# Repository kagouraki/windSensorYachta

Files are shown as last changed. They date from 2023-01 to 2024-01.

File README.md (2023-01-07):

## Windsensor Yachta

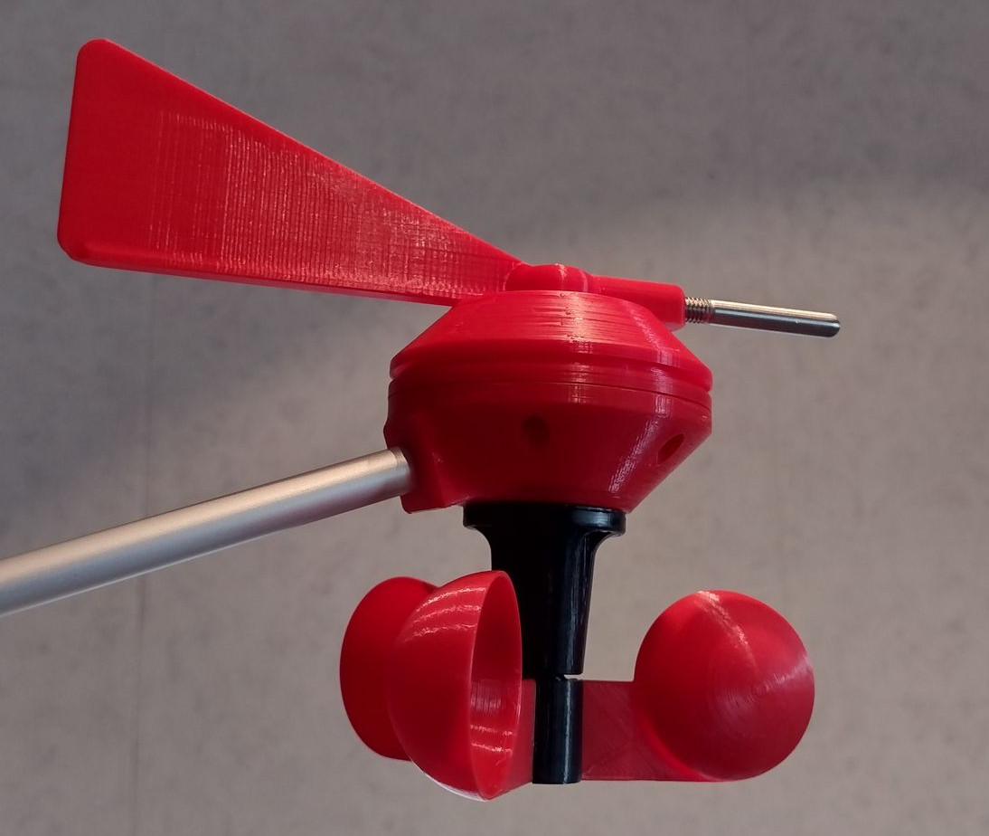
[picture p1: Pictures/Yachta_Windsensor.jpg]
Windsnesor Yachta


Image: Wind Sensor Yachta

The initial idea for the Yachta wind sensor is based on a work by the user Yachta. He presented and published the wind sensor on [Thingiverse](https://www.thingiverse.com/thing:2261719). Udo took up the idea of Yachta and modified the mechanics a little. The arms of the cup wheel have been separated. This makes 3D printing easier to implement. The electronics were completely redesigned by him. The microcontroller was removed and replaced with an ESP8266. A DC/DC converter module was installed so that the wind sensor can also be operated at 12V. The circuit board was created with the Windows software Sprint Layout and converted into Gerber files. Now is a new BCP available from Norbert.

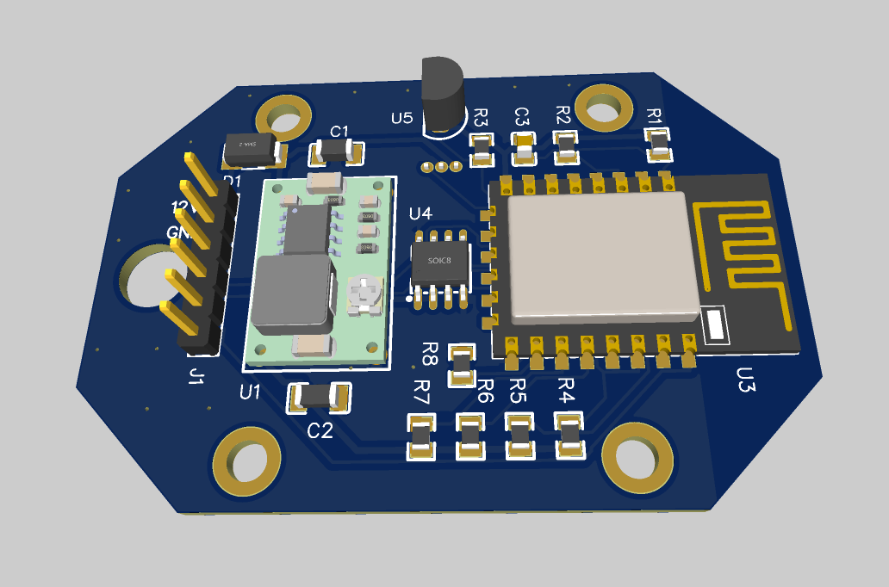
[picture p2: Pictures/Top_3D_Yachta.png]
Windsnesor Yachta


Image: PCB board

The PCB project is listed on [Open Source Hardware Lab](https://oshwlab.com/) an can be edited with the webbased online [layout program EasyEDA](https://easyeda.com/norbert-walter/projects).

The board without components can be ordered from [Aisler](https://aisler.net/p/VTNPJWKQ) or direct in EasyEDA.

There are different firmware for the wind sensor. Both Udo and Julian ([Jukolein](https://github.com/jukolein/NMEA0183-Windsensor)) have created their own firmware versions with different functionality. Udo has also designed another wind sensor, which is a further development of the Yachta wind sensor. The functional principle and the electronics are identical. But you need a different board because the wind sensor is slimmer. Julian published the whole thing on [Github](https://github.com/jukolein/NMEA0183-Windsensor) and wrote his own firmware for the wind sensor, which can also be used for this wind sensor. 

The WiFi 1000 firmware is a firmware that can be used universally for various wind sensors and was originally developed by Norbert for the [WiFi 1000 wind sensor](https://gitlab.com/norbertwalter67/Windsensor_WiFi_1000). The current versions of the firmware can be found in the respective own repositories at Github and GitLab.

A lively exchange of experiences takes place in the German-speaking [sailing forum](https://www.segeln-forum.de/board194-boot-technik/board195-open-boat-projects-org/79131-windsensor-ii-iii/). You can also participate in English.

If you like to help or consider this project useful, please donate. Thanks for your support!

Donate (https://www.paypal.com/cgi-bin/webscr?cmd=_s-xclick&hosted_button_id=5QZJZBM252F2L)

## Technical characteristics

* Measuring wind speed and wind direction 
* Robust mechanics
* Without special metal parts
* All parts can be found in the hardware store
* Easy 3D parts
* Weight app. 210g
* Weatherproof and UV stable
* No cabling for sensor signals
* Digital signal transmission with WiFi only
* 12V power supply utilizing top light power cable
* Using a ESP8266 for WiFi and data handling
* Update rate 1 samples per second
* No onboard instrument required
* Visualisation in OpenPlotter via laptop, mobile fone or tablett
* Web interface for operation
* No extra software required (display is the browser)
* Supporting  NMEA 0183 protocol
* Firmware update via Internet

## Firmware characteristics

**Udo Firmware**
* Web configuration for IP settings port 80
* UDP port 2948
* UDP NMEA0183 telegram MWV

**Jukolein Firmware**
* Web configuration and grafical visualisation
* Webserver port 80
* UDP port 8080
* TCP port 8080
* UDP/TCP NMEA0183 telegram MWV
* Firmware update OTA via Arduino IDE

**Wifi 1000 Firmware**
* Web configuration and graphical visualisation
* Webserver port 80
* TCP port 6666
* TCP NMEA0183 telegram MWV, VWR, VPW, INF
* JSON http://192.168.4.1/json
* Firmware update via Internet
* Android App

## How can I use it?

I use the windsensor in combination with [OpenPlotter](http://www.sailoog.com/openplotter) on a Raspberry Pi 3B. OpenPlotter serves as access point for WiFi devices. The windsensor connects to OpenPlotter via WiFi and transmits the NMEA0183 data telegrams every second. The windsensor sends NMEA0183 telegrams. Check here [link](http://www.nmea.de/nmea0183datensaetze.html) for more information. 

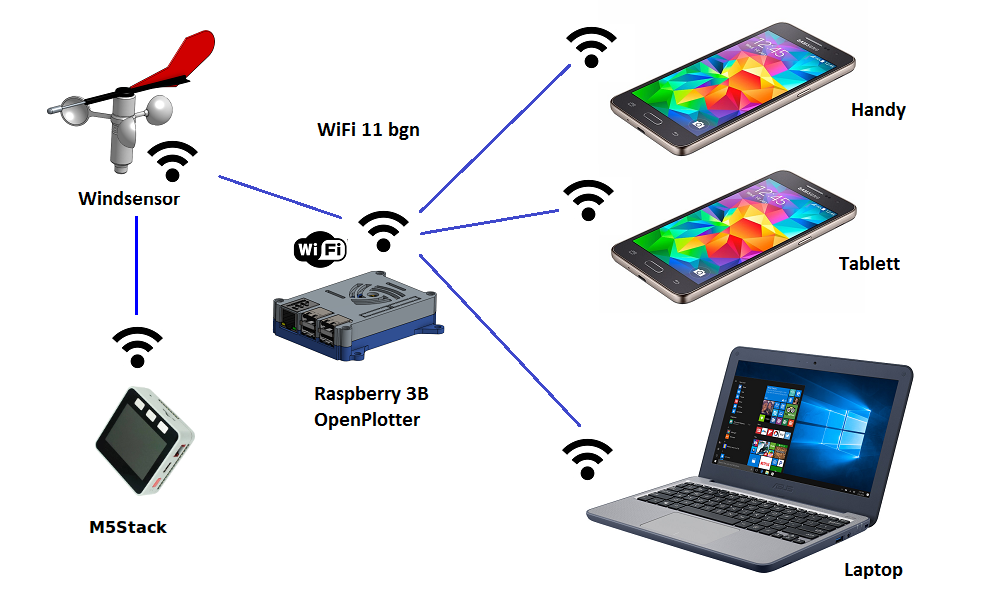
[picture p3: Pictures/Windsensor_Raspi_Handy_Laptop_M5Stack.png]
Connectivity


Img: Connection options

A Android App is also available. It is is a WebApp connecting directly to the windsensor to display all data.

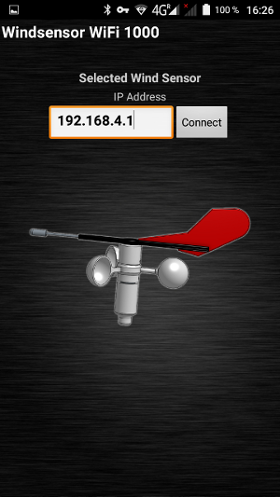
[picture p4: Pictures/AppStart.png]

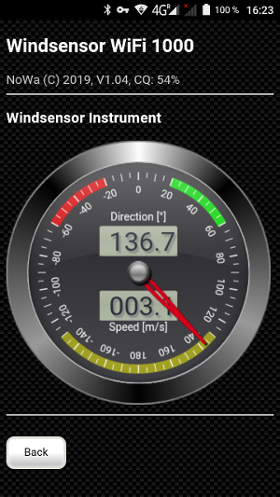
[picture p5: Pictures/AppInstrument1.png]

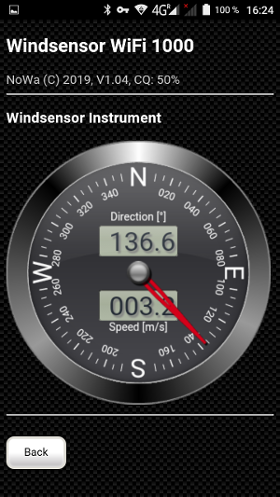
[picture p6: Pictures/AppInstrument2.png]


Img: Android App for Wifi 1000 firmware

## What is the current status?

I have completed many tasks but still not everything is perfect so far.

- [x] Technical recherche
- [x] Evaluation of function
    - [x] Hall sensors and rotation sensor
    - [x] Magnets
    - [x] Prototype circuit
    - [x] Test software
    - [x] Web display technologies
    - [x] 3D material test
    - [x] Coating tests
- [x] Mechanical design
    - [x] 3D parts
- [ ] Electronic design
    - [x] Circuit design
    - [x] Board design
    - [ ] Customer sample circuit
- [ ] Software
    - [x] Basic functionality
    - [x] NMEA0183 WiFi
    - [x] NMEA0183 Serial
    - [x] mDNS Service
    - [x] JSON
    - [ ] MQTT
    - [ ] Wind History Diagram
    - [x] Sensor Data Diagram for diagnostic and mechanical adjustment
    - [x] Web-Updater
    - [x] Web-Configurator
    - [x] Web server as data display
    - [x] Andoid App
    - [x] External Diagnostic Tool
	- [x] Support for other wind sensor types
- [x] Components ordering
    - [x] Electronic board
    - [x] Mechanical parts
    - [x] Fittings
- [x] Prototyp creation
    - [x] Yachta prototype
    - [x] Modifyed Yachta prototype
- [x] Production Zero series
    - [x] Assembled and programed PCB
- [x] Shipping Zero Series
- [ ] Documentation
    - [ ] Technical description
	- [x] Description Web frontend
    - [x] Construction manual
    - [x] Part list
    - [ ] User manual
    - [ ] Data sheet
- [ ] Application tests
    - [x] Temperature 20...80°C
    - [ ] Vibration test by strong wind (8bft)
    - [x] WiFi stability test
    - [x] Connection test
    - [ ] Rain test
    - [ ] IPX6 Water resistance test
    - [ ] UV radiation test
    - [ ] Long time test
    - [ ] Test with auto pilot
    - [x] User experiences
- [ ] Extensions
    - [x] Multi function display with M5Stack
    - [x] NMEA2000 Gateway
    - [x] Weather data sensor with BME280
- [ ] Certification
    - [ ] CE Certification

## Questions?

For questions or suggestions please get in contact via email at norbert-walter(at)web.de.

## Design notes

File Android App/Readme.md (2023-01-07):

The Android app was programmed with [MIT App Inventor](http://ai2.appinventor.mit.edu/?locale=en). Programming is very simple and is done graphically using blocks. The file with the extension * .aia can be loaded into MIT App Inventor and processed further. The apk file is used for installation under Android.

The security precautions are increased under Android 11 and the apk file cannot be downloaded and installed directly on the mobile phone. An installation is then refused and the file type is changed. To install third-party software outside of the PlayStore, the apk file must be transferred to the downloads folder on the mobile phone via a USB connection. The Android app can then be installed via the file manager. 

{- This App is only usable for the wiFi 1000 firmware -}

**2021 Windsensor_WiFi_1000_6.apk {+ (stable) +}**

* First universal App for Yachta and other wind sensors
* Saving the last IP in a data base
* If the App running then disable the display timeout
* Checking the type of connection (is this a wind sensor)
* Reading the device type from JSON
* Open the following page only if detect a wind sensor
* Error handling by incorrect connections (messaging)

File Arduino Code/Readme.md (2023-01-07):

## Firmware Information

The directories for the firmware versions only contain old software versions that i have modified. Use the following links for current software versions:

[WiFi 1000 Firmware](https://gitlab.com/norbertwalter67/Windsensor_WiFi_1000)

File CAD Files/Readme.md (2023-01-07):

## Information

If you need eany changes on the PCB then you can use EasyEDA. The project is located on [Open Source Hradware Lab (OSHWLab)](https://oshwlab.com/kagouraki/wind).

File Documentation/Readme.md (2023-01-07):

## Information

An illustrated assembly instruction can be found in the folder [Picutures/Yachta_Thingiverse](https://gitlab.com/norbertwalter67/windsensor_yachta/-/tree/main/Pictures/Yachta_Thingiverse). Due to the changes made by Udo, there are small deviations in the instructions from Yachta. But it shouldn't cause any problems to assemble the wind sensor.

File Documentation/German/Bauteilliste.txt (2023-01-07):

Material:
#########

11x Holzschraube 3x16 oder Inbusschraube M3x10
1x Inbusschraube M6 x 60 mit glattem Schaft 35 mm
1x Kreuzschlitzschraube M5 x 60
1x Senkkopfschraube M5 x 25
2x Stopmutter M5
1x Mutter M5
2x Kugellager 16x5x5 (625)
1x Kugellager 13x5x4 (695) oder Keramik für unten
3x U-Scheibe M5     
4x Neodym Magnete 1x1,5x5
1x Neodym Magnet Viereck 5x5x5

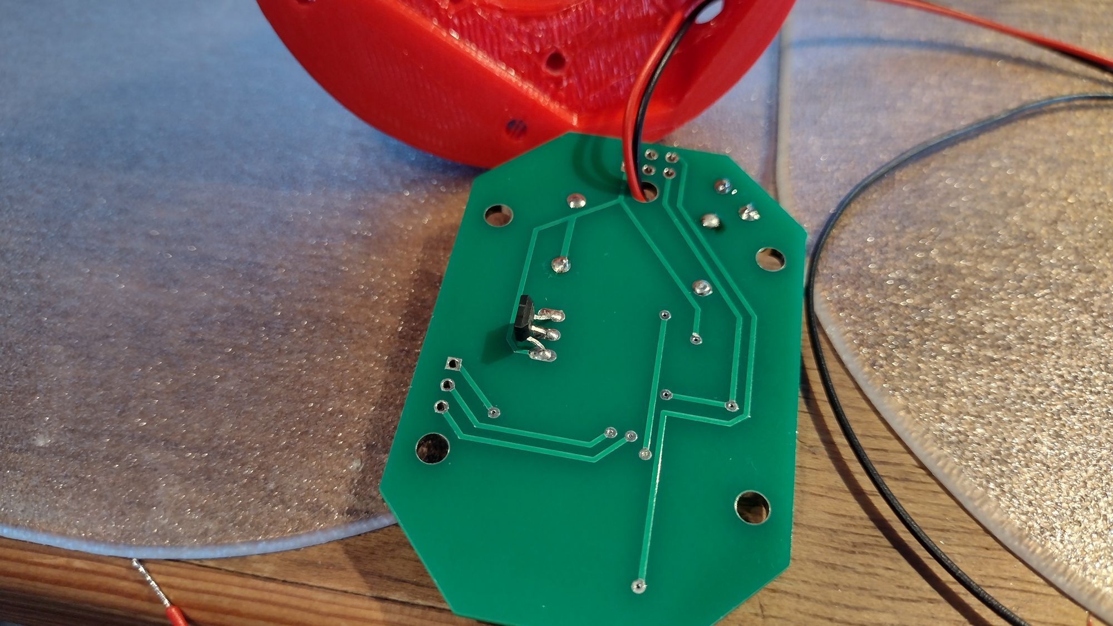
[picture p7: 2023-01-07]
Pictures/Yachta_Details/IMG_20210728_144107366_HDR_kl.jpg

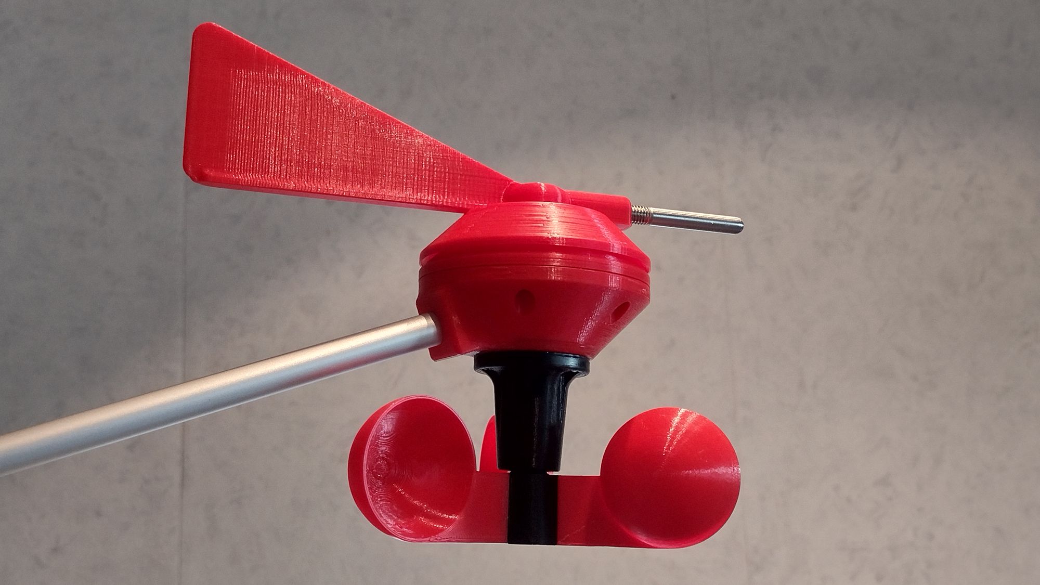
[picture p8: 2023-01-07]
Pictures/Yachta_Details/IMG_20210811_103233046_HDR_kl.jpg

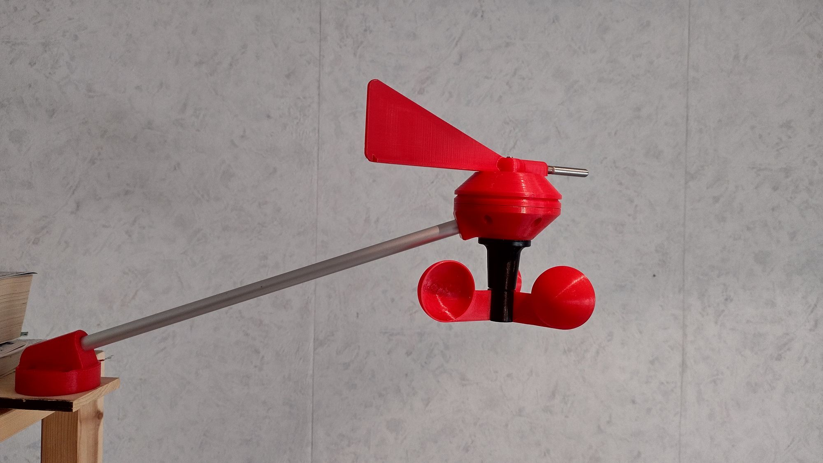
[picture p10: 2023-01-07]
Pictures/Yachta_Details/IMG_20210811_104626496_HDR_kl.jpg

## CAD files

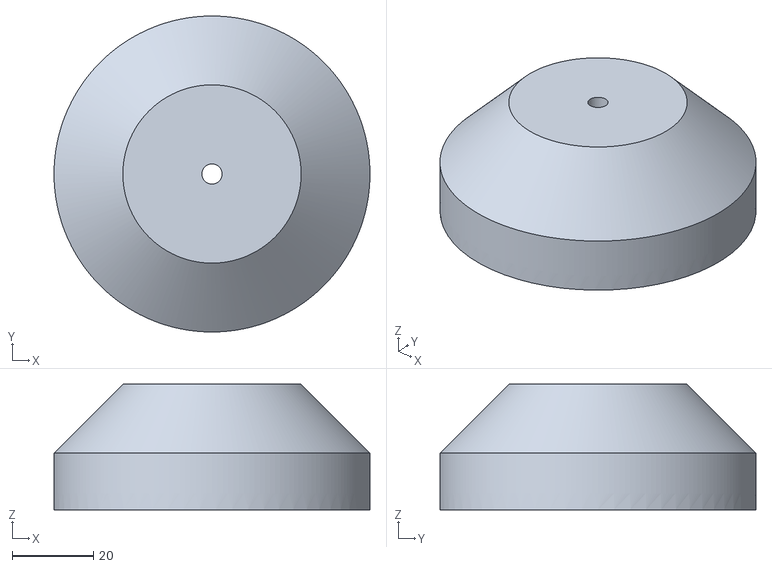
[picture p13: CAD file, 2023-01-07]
CAD Files/3D-Parts/fane_support_big.STL
78.0 x 78.0 x 31.0

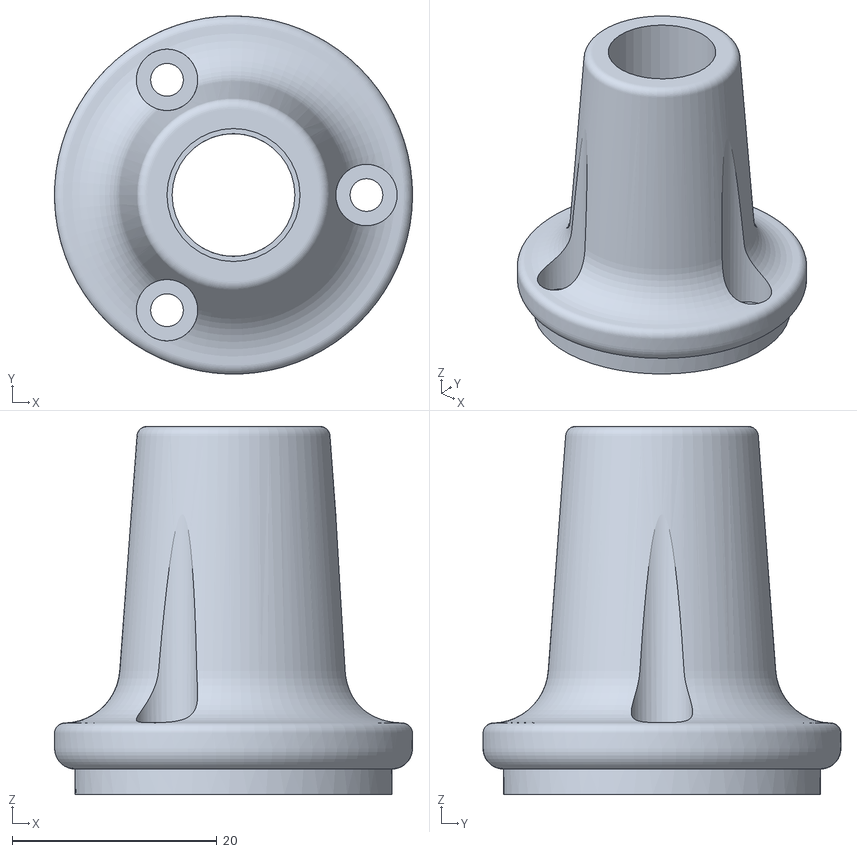
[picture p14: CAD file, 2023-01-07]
CAD Files/3D-Parts/Unterteil-2.STL
35.0 x 35.0 x 36.0

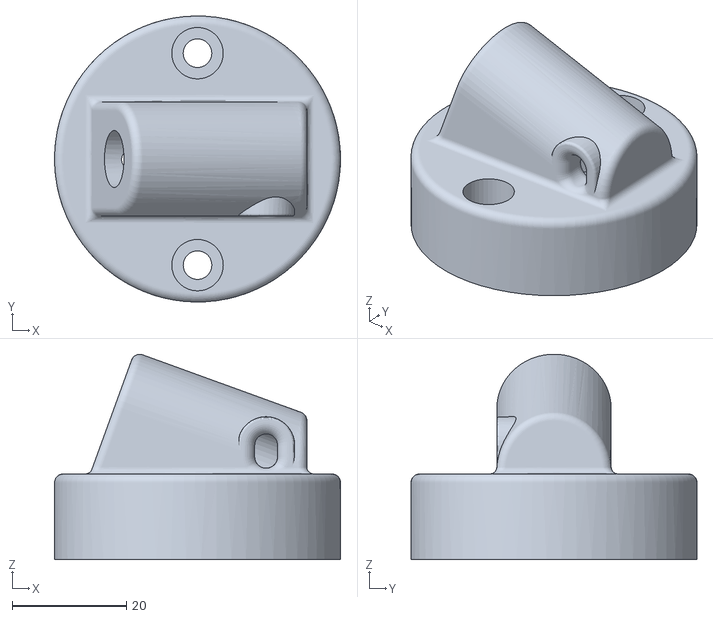
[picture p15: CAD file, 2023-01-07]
CAD Files/3D-Parts/Fuss_regler.STL
50.0 x 50.0 x 35.9

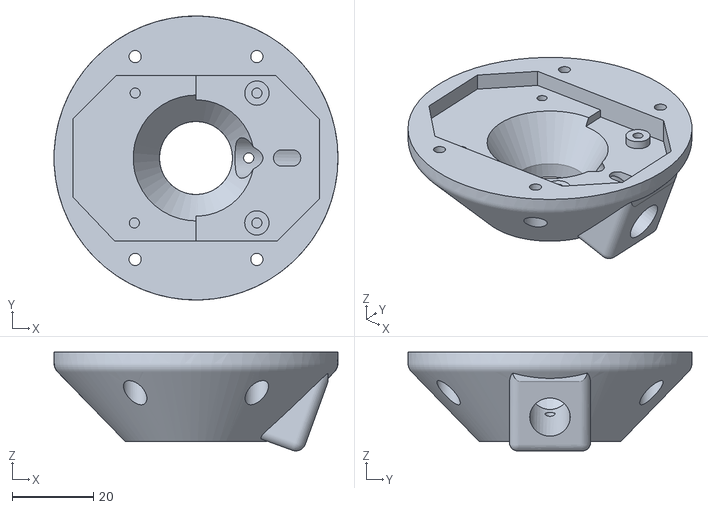
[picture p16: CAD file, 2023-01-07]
CAD Files/3D-Parts/Unterteil.STL
70.0 x 70.0 x 24.4

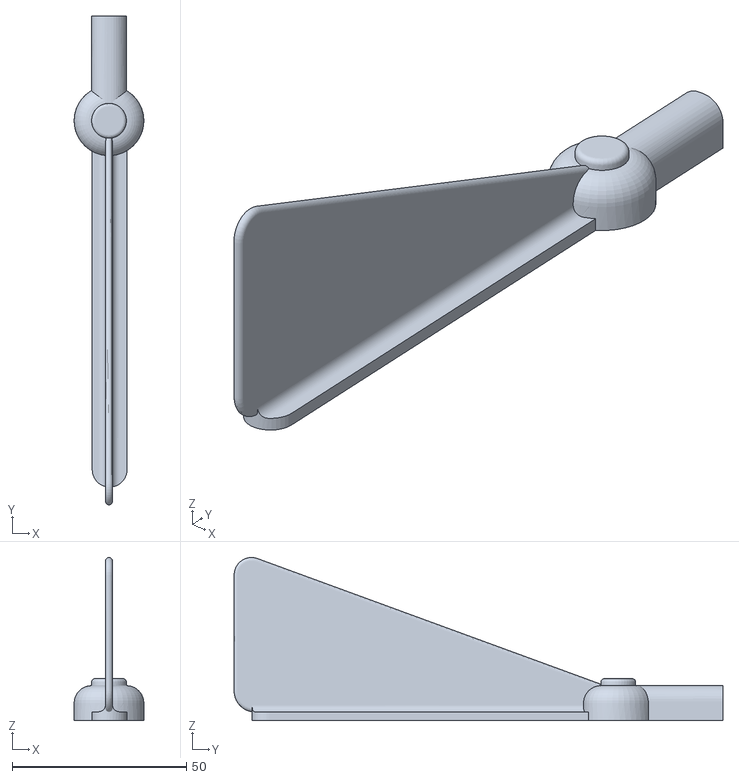
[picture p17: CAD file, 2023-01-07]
CAD Files/3D-Parts/Windfahne.STL
20.0 x 140.1 x 46.7

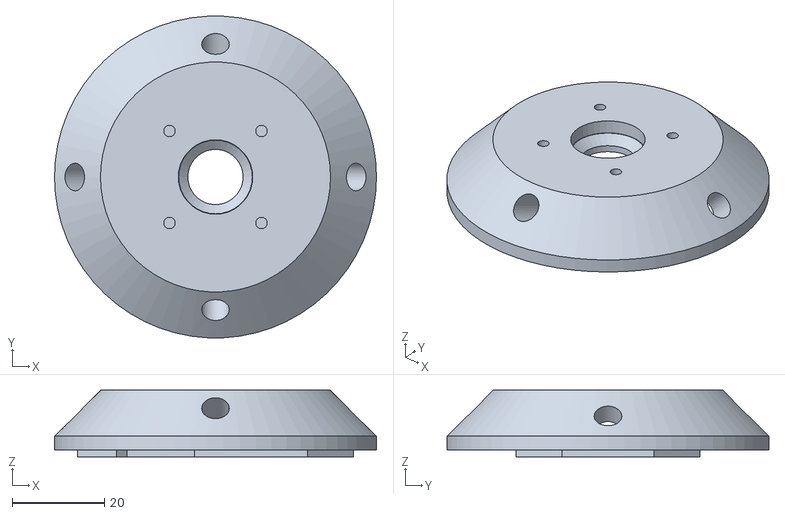
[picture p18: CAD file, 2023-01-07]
CAD Files/3D-Parts/Oberteil.STL
70.0 x 69.9 x 14.5

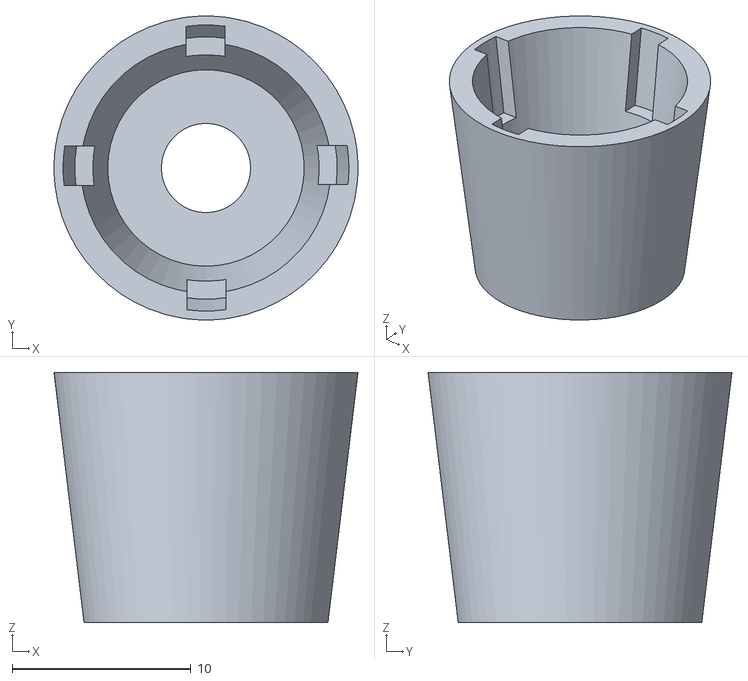
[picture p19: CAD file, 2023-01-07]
CAD Files/3D-Parts/Magnethalter.STL
17.0 x 17.0 x 14.0

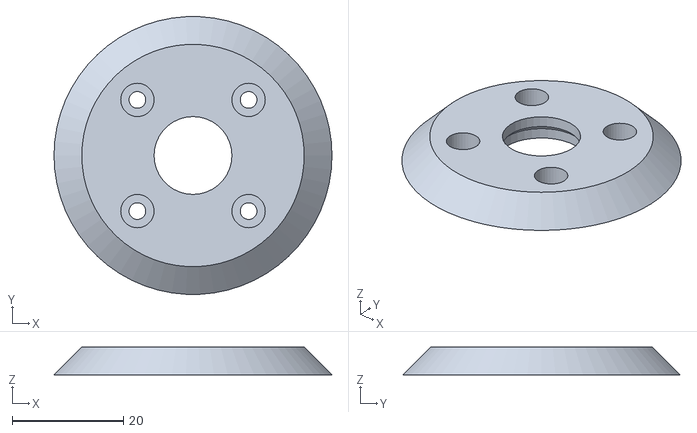
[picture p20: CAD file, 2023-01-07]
CAD Files/3D-Parts/Oberteil3.STL
50.0 x 49.9 x 5.00

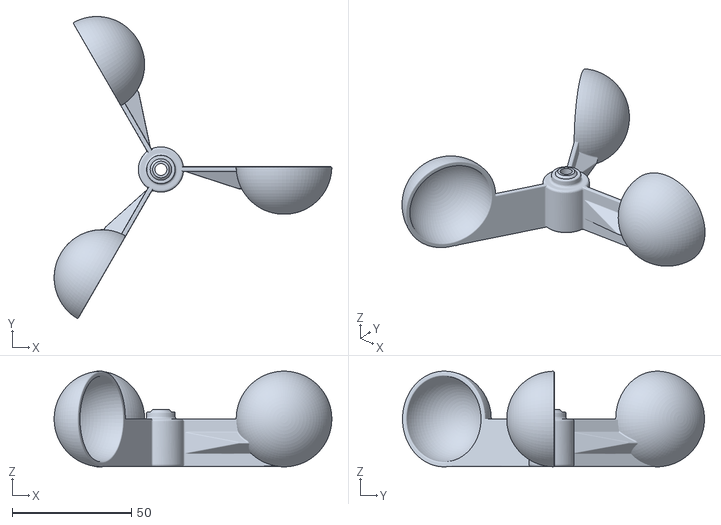
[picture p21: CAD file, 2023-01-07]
CAD Files/3D-Parts/Cups.STL
116.6 x 126.8 x 40.2

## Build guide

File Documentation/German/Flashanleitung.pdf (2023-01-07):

# Flash-Anleitung

# Windsensor WiFi 1000

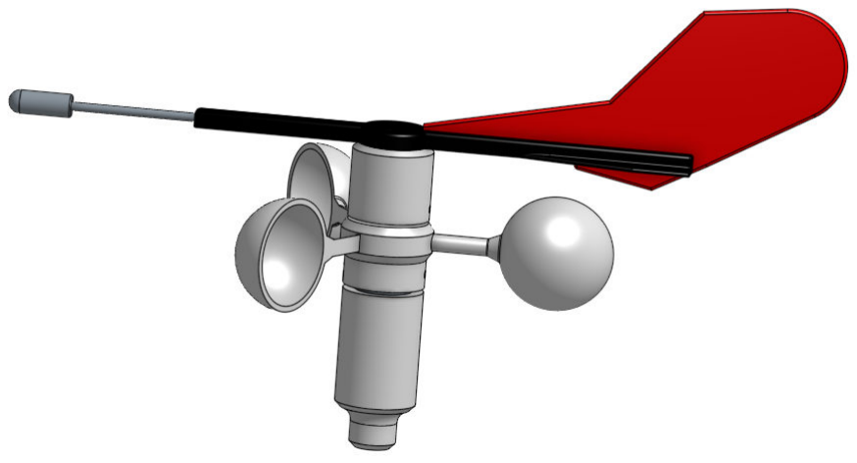
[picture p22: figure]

NoWa | Flash-Anleitung – Windsensor WiFi 1000
2/5 | Vers.: 13.03.2020
Ersteller | Norbert Walter
| Wiesbadener Str. 1 40225 Düsseldorf
| norbert-walter@web.de

© Die Technische Beschreibung unterliegt der Creative Common Lizenz

Flash-Anleitung – Windsensor WiFi 1000 | NoWa
Vers.: 13.03.2020 | 3/5

### Inhalt

NoWa | Flash-Anleitung – Windsensor WiFi 1000

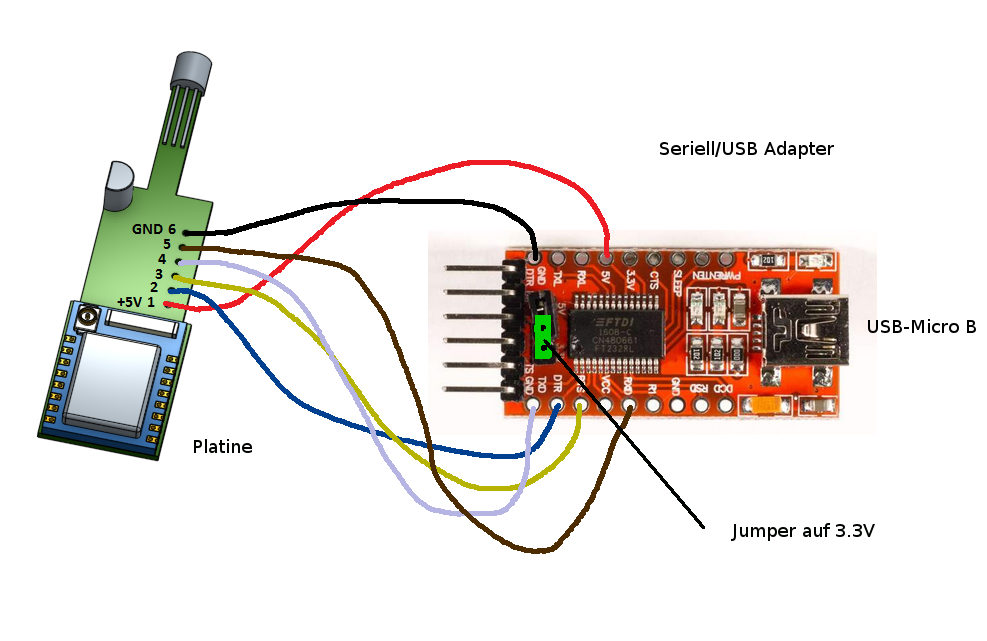
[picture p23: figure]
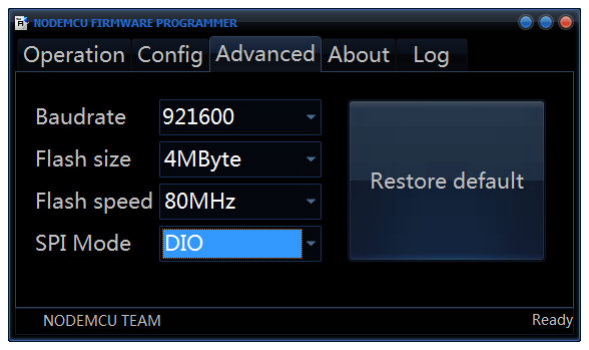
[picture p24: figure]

4/5 | Vers.: 13.03.2020

## 1 Firmware flashen

Falls es notwendig ist die Firmware des Windsensors zu flashen, dann kann dies über ein Seriell/USB-Adapter erfolgen. Es ist darauf zu achten, dass der Adapter 3,3V TTL-Signale verarbeiten kann und über folgende Anschlüsse verfügt:

Kürzel | Pin | Bedeutung
+5V | 1 | Versorgungsspannung 5V
DTR | 2 | Programmierung (Reset)*
RTS | 3 | Programmierung (Aktivierung Flashvorgang)*
TXD | 4 | Sendedaten*
RXD | 5 | Empfangsdaten*
GND | 6 | Masse
| | * Signalpegel 3,3V TTL

Der Adapter wird dann mit der Platine des Windsensors wie folgt verbunden.

Abb.: Anschluss des Programmieradapters

Die Datenübertragung erfolgt dann über die USB-Schnittstelle des Adapters. Zum Flashen der Firmware wird das Tool NodeMCU flasher benötigt, dass es leider nur für das Betriebssystem Windows als 32Bit und 64Bit Version gibt. Es kann unter dieser Adresse heruntergeladen werden:

https://github.com/nodemcu/nodemcu-flasher

Die EXE-Datei kann ohne spezielle Installation direkt gestartet werden. Als erstes werden unter Advanced folgende Einstellungen vorgenommen.

Danach wird unter Config die Firmwaredatei firmware_Vx.xx.wsb ausgewählt.

Flash-Anleitung – Windsensor WiFi 1000 | NoWa
Vers.: 13.03.2020 | 5/5

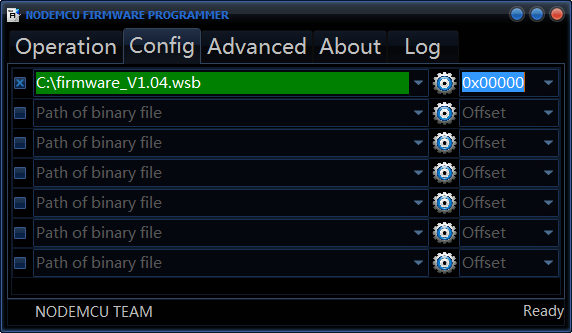
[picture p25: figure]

Zum Flashen geht man auf Operation und wählt die entsprechende Schnittstelle aus an der der Adapter angeschlossen ist. Danach drückt man auf Flash und wartet ab, bis die Firmware geladen ist.

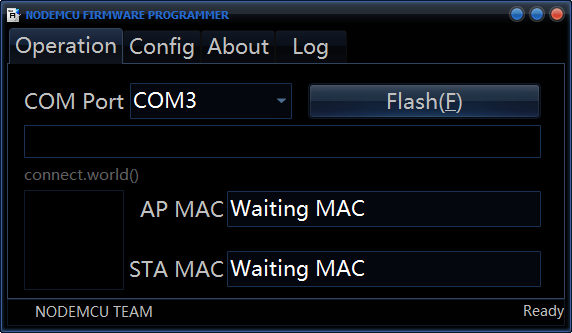
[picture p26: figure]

Während des Flashens wird der Fortschritt der Übertragung angezeigt.

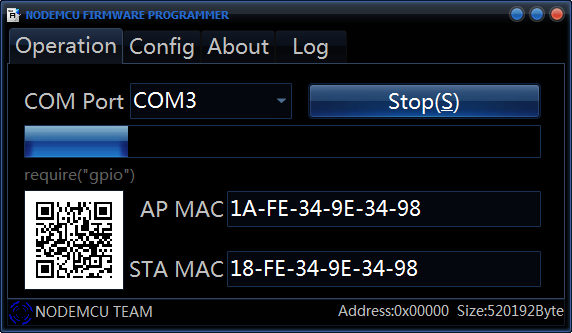
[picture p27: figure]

Wenn die Firmware erfolgreich geladen wurde ist folgender Bildschirm zu sehen.

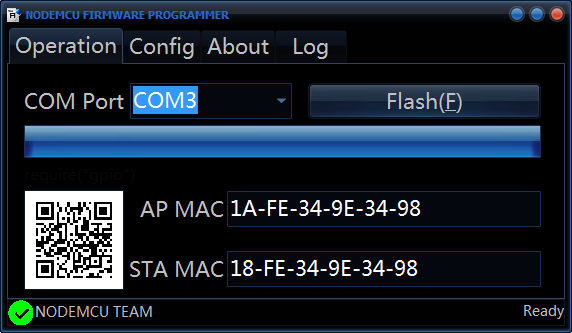
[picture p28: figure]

Nach der Übertragung kann das Programmiertool geschlossen und der Adapter abgezogen werden. Um die neue Firmware zu starten benötigt der Windsensor einen Reboot.

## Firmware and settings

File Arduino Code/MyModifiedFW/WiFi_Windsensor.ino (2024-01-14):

//*********************************************************************************************
// WiFi and NMEA server for transmitting wind sensor data via TCP connection
// (C) Norbert Walter 2021
// License: GNU GPL V3
// https://www.gnu.org/licenses/gpl-3.0.txt
//
// WiFi_Windsensor.ino
//
// Tested and compiled with Arduino IDE 1.8.5
// Board esp8266 V2.5.2 (SDK 2.2.1 (cfd48f3))
// The server use different NMEA centeces
//
// Wind direction and speed:  $WIMWV,x.x,a,x.x,a,A*hh
// Wind direction and speed:  $WIVWR,x.x,a,x.x,N,x.x,M,x.x,K*hh
// Down wind speed:           $WIVPW,x.x,N,x.x,M*hh                               (Wind speed parallel to wind direction)
// Wind speed informations:   $PWINF,0,x.x,D,x.x,D,x.x,M,x.x,K,x.x,N,x.x,B,A*hh   (Custom sentence)
// Wind sensor temperature:   $PWWST,C,0,x.x,A*hh                                 (Custom sentence)
// Enviromental readings      $WIMDA,,,x.x,B,x.x,C,,,x.x,,x.x,C,,,,,,,*hh
//
//*********************************************************************************************

// Includes
#include <ESP8266WiFi.h>    // WiFi lib with TCP server and client

#include <WiFiClient.h>             // WiFi lib for clients
#include <ESP8266WebServer.h>       // WebServer lib
#include <ESP8266mDNS.h>            // DNS lib
#include <ESP8266HTTPUpdateServer.h>// Web Update server

#include <Ticker.h>         // Timer lib
#include <EEPROM.h>         // EEPROM lib
#include <WString.h>        // Needs for structures
#include <OneWire.h>        // 1Wire network lib
#include <Wire.h>           // Lib for I2C
#include <Adafruit_Sensor.h>// Adafuit sensor lib
#include <Adafruit_BME280.h>// Lib for BME280
#include <AS5600.h>         // Lib for magnetic rotation sensor AS5600
#include <DallasTemperature.h>// Dallas 1Wire lib
#include <SimplyAtomic.h>   // This library includes the ATOMIC_BLOCK macro
#include "Configuration.h"  // Setup data structure in header file
#include "Definitions.h"    // Local definitions in additional file

AS5600 ams5600;           // Declare magnetic rotation sensor AS5600
Adafruit_BME280 bme;        // Declare environment sensor BME280
OneWire oneWire(ONE_WIRE_BUS); // Declare 1Wire
DallasTemperature DS18B20(&oneWire); // Declare DS18B20
configData actconf;         // Actual configuration, Global variable
// Overload with old EEPROM configuration by start. It is necessarry for port and serspeed
// Don't change the position!

#include "Calculation.h"    // Function library for wind data calculation
#include "FunctionsLib.h"   // Function library
#include "NMEATelegrams.h"  // Function library for NMEA telegrams
#include "icon_html.h"      // Favorit icon
#include "css_html.h"       // CSS cascading style sheets
#include "steel_html.h"     // JavaScript steelseries_micro.js.gz library
#include "tween_html.h"     // JavaScript tween-min.js.gz library
#include "js_html.h"        // JavaScript functions
#include "main_html.h"      // Main webpage
#include "settings_html.h"  // Settings webpage
#include "firmware_html.h"  // Firmware update webpage
#include "json_html.h"      // JSON webpage
#include "json2_html.h"     // JSON webpage for Hall sensor signals
#include "MD5_html.h"       // JavaScript crypt password with MD5
#include "restart_html.h"   // Reset info webpage
#include "devinfo_html.h"   // Device info webpage
#include "windv_html.h"     // Wind value webpage
#include "windi_html.h"     // Wind instrument webpage
#include "error_html.h"     // Error 404 webpage

// Declarations
int value;                  // Value from first byte in EEPROM
int empty;    // If EEPROM empty without configutation then set to 1 otherwise 0
configData defconf;         // Definition of default configuration data
configData oldconf;      // Configuration stucture for old config data in EEPROM
configData newconf;      // Configuration stucture for new config data in EEPROM

ESP8266WebServer httpServer(actconf.httpport);  // Port for HTTP server
ESP8266HTTPUpdateServer httpUpdater;            // Declaration update server
MDNSResponder mdns;                             // Activate DNS responder

Ticker Timer2;              // Declare Timer2 for average building
Ticker Timer3;              // Declare Timer3 for normal NMEA data sending
Ticker Timer4;              // Declare Timer4 for reduced NMEA data sending
Ticker Timer5;  // Declare Timer5 for calculation of windspeed und winddirection
WiFiServer server(actconf.dataport);  // Declare WiFi NMEA server port
IPAddress ip(192, 168, 10, 1);
IPAddress gateway(192, 168, 10, 1);
IPAddress subnet(255, 255, 255, 0);

const int maxTCPclients = 5;
WiFiClient serverClients[maxTCPclients];


//*********************************************************************************************
// Setup section
//*********************************************************************************************
void setup() {
	// Start bus systems
	Wire.begin();                        // Start I2C
	bme.begin(i2cAddressBME280);         // Start BME280

	// !!!!!! Uncomment this line if you using a new configuration structure !!!!!!
	//  saveEEPROMConfig(defconf);

	// Read the first byte from the EEPROM
	EEPROM.begin(sizeEEPROM);
	value = EEPROM.read(cfgStart);
	EEPROM.end();
	// If the fist Byte not identical to the first value in the default configuration then saving a default configuration in EEPROM.
	// Means if the EEPROM empty then saving a default configuration.
	if (value == defconf.valid) {
		empty = 0;                  // Marker for configuration is present
	} else {
		saveEEPROMConfig(defconf);
		empty = 1;                  // Marker for configuration is missing
	}

	// Loading EEPROM configuration
	actconf = loadEEPROMConfig(); // Overload with old EEPROM configuration by start. It is necessarry for serspeed

	// If the firmware version in EEPROM different to defconf then save the new version in EEPROM
	if (String(actconf.fversion) != String(defconf.fversion)) {
		String fver = defconf.fversion;
		fver.toCharArray(actconf.fversion, 6);
		saveEEPROMConfig(actconf);
	}

	// Pin definitions and settings for wind sensor types Yachta and Jukolein
	if (String(actconf.windSensorType) == "Jukolein") {

		// Pin redefinition for other wind sensor types (Original values see Definition.h)
		// Attention! GPIO 12 is not available! (1Wire)
		// Existing pins
		ledPin = 14;                // LED GPIO 14 (fake) (D5)
		INT_PIN1 = 2;               // Wind speed GPIO 2 (Hall sensor) (D4)
		INT_PIN2 = 16;         // Wind direction GPIO 16 (Hall sensor fake) (D0)
		// New pins
		int SCL = 5;  // Wind direction magnetic sensor SCL GPIO 5 (AS5600) (D1)
		int SDA = 4;  // Wind direction magnetic sensor SDA GPIO 4 (AS6500) (D2)
	}

	// Pin definitions and settings for wind sensor types Ventus
	if (String(actconf.windSensorType) == "Yachta"
			|| String(actconf.windSensorType) == "Ventus") {

		// Pin redefinition for other wind sensor types (Original values see Definition.h)
		// Attention! GPIO 12 is not available! (1Wire)
		// Existing pins
		ledPin = 2;                 // LED GPIO 2 (D4)
		INT_PIN1 = 14; // Wind speed GPIO 14 (Reed switch) (D5), pin need 10k and 100n for spike reduction
		INT_PIN2 = 16;         // Wind direction GPIO 16 (Hall sensor fake) (D0)
		// New pins
		int SCL = 5;  // Wind direction magnetic sensor SCL GPIO 5 (AS5600) (D1)
		int SDA = 4;  // Wind direction magnetic sensor SDA GPIO 4 (AS6500) (D2)
	}

	// Pin settings
	pinMode(INT_PIN1, INPUT_PULLUP);  // Interrupt input 1 speed
	pinMode(INT_PIN2, INPUT_PULLUP);  // Interrupt input 2 direction
	pinMode(ledPin, OUTPUT);          // LED Pin output
	digitalWrite(ledPin, LOW);        // Switch LED on (inverted!)

	Serial.begin(actconf.serspeed);   // Start serial communication
	delay(10);

	//  DebugPrint(3, "First EEPROM byte: ");
	//  DebugPrintln(3, value);

	// ESP8266 Information Data
	DebugPrintln(3, "Booting Sketch...");
	DebugPrint(3, actconf.devname);
	DebugPrint(3, " ");
	DebugPrint(3, actconf.windSensorType);
	DebugPrint(3, " ");
	DebugPrint(3, actconf.fversion);
	DebugPrintln(3, " (C) Norbert Walter");
	DebugPrintln(3, "*********************************************");
	DebugPrintln(3, "");
	DebugPrintln(3, "Modul Type: ESP8266");
	DebugPrint(3, "SDK-Version: ");
	DebugPrintln(3, ESP.getSdkVersion());
	DebugPrint(3, "ESP8266 Chip-ID: ");
	DebugPrintln(3, ESP.getChipId());
	DebugPrint(3, "ESP8266 Speed [MHz]: ");
	DebugPrintln(3, ESP.getCpuFreqMHz());
	DebugPrint(3, "Free Heap Size [Bytes]: ");
	DebugPrintln(3, ESP.getFreeHeap());
	DebugPrintln(3, "");
	DebugPrint(3, "Sensor ID: ");
	DebugPrintln(3, actconf.sensorID);
	DebugPrint(3, "Wind Sensor Type: ");
	DebugPrintln(3, actconf.windSensorType);
	DebugPrintln(3, "Sensor Type: Wind Speed");
	DebugPrint(3, "Input Pin: GPIO ");
	DebugPrintln(3, INT_PIN1);
	DebugPrintln(3, "Value Range [kn]: 0...73");
	DebugPrint(3, "Sensor Type: ");
	if (String(actconf.windType) == "R") {
		DebugPrintln(3, "Relative ");
	} else {
		DebugPrintln(3, "True ");
	}
	if (String(actconf.windSensorType) == "WiFi 1000") {
		DebugPrintln(3, "Wind direction");
		DebugPrint(3, "Input Pin: GPIO ");
		DebugPrintln(3, INT_PIN2);
		DebugPrintln(3, "Value Range [°]: 0...360");
	}
	if (String(actconf.windSensorType) == "Yachta"
			|| String(actconf.windSensorType) == "Jukolein"
			|| String(actconf.windSensorType) == "Ventus") {
		DebugPrintln(3, "Wind direction: AS5600");
		DebugPrint(3, "SCL: GPIO ");
		DebugPrintln(3, SCL);
		DebugPrint(3, "SDA: GPIO ");
		DebugPrintln(3, SDA);
		DebugPrint(3, "Scan I2C at address 0x");
		if (i2cAddressAS5600 < 0x10) {
			DebugPrint(3, "0");
		}
		DebugPrint(3, String(i2cAddressAS5600, HEX));
		DebugPrint(3, ": ");
		Wire.beginTransmission(i2cAddressAS5600);
		if (Wire.endTransmission() == 0) {
			i2creadyAS5600 = 1;                        // Result I2C scan
			DebugPrintln(3, "ready");
			DebugPrint(3, "Magnitude [1]: ");
			DebugPrintln(3, ams5600.getMagnitude());
			DebugPrint(3, "Raw Angle [°]: ");
			magsensor = ams5600.getRawAngle() * 0.087; // 0...4096 which is 0.087 of a degree
			DebugPrintln(3, magsensor);
		} else {
			i2creadyAS5600 = 0;                        // Result I2C scan
			DebugPrintln(3, "error");
			DebugPrintln(3, "Stop I2C for device AS5600");
		}
	}
	//if (String(actconf.windSensorType) == "Ventus") {
	if (String(actconf.tempSensorType) == "BME280") {
		DebugPrintln(3, "Environment Sensor: BME280");
		DebugPrint(3, "SCL: GPIO ");
		DebugPrintln(3, SCL);
		DebugPrint(3, "SDA: GPIO ");
		DebugPrintln(3, SDA);
		DebugPrint(3, "Scan I2C at address 0x");
		if (i2cAddressBME280 < 0x10) {
			DebugPrint(3, "0");
		}
		DebugPrint(3, String(i2cAddressBME280, HEX));
		DebugPrint(3, ": ");
		Wire.beginTransmission(i2cAddressBME280);
		if (Wire.endTransmission() == 0) {
			i2creadyBME280 = 1;                        // Result I2C scan
			DebugPrintln(3, "ready");
			DebugPrint(3, "Temperature [°C]: ");
			airtemperature = bme.readTemperature();
			DebugPrintln(3, airtemperature);
			DebugPrint(3, "Air Pressure [mbar]: ");
			airpressure = bme.readPressure() / 100;
			DebugPrintln(3, airpressure);
			DebugPrint(3, "Air Humidity [%]: ");
			airhumidity = bme.readHumidity();
			DebugPrintln(3, airhumidity);
			DebugPrint(3, "Altitude [m]: ");
			altitude = bme.readAltitude(SEALEVELPRESSURE_HPA);
			DebugPrintln(3, altitude);
		} else {
			i2creadyBME280 = 0;                        // Result I2C scan
			DebugPrintln(3, "error");
			DebugPrintln(3, "Stop I2C for device BME280");
		}
	}
	if (String(actconf.tempSensorType) == "DS18B20") {
		DebugPrintln(3, "Sensor Type: Sensor Temp 1Wire");
		DebugPrint(3, "Input Pin: GPIO ");
		DebugPrintln(3, ONE_WIRE_BUS);
		DebugPrintln(3, "Value Range [°C]: -55...125");
	}
	DebugPrint(3, "Send Period [ms]: ");
	DebugPrintln(3, SendPeriod);
	DebugPrint(3, "Reduced Send Period [ms]: ");
	DebugPrintln(3, RedSendPeriod);
	DebugPrintln(3, "");

	// Debug info for initialize the EEPROM
	if (empty == 1) {
		DebugPrintln(3, "EEPROM config missing, initialization done");
	} else {
		DebugPrintln(3, "EEPROM config present");
	}

	// Loading EEPROM config
	DebugPrintln(3, "Loading actual EEPROM config");
	actconf = loadEEPROMConfig();
	DebugPrintln(3, "");

	// Starting access point for update server
	WiFi.mode(WIFI_AP_STA);
	WiFi.setSleepMode(WIFI_NONE_SLEEP);
	WiFi.softAPConfig(ip, gateway, subnet);
	WiFi.softAP(actconf.sssid, actconf.spassword, actconf.apchannel, false,
			actconf.maxconnections);
	DebugPrint(3, "Access point started with SSID ");
	DebugPrintln(3, actconf.sssid);
	DebugPrint(3, "Access point channel: ");
	DebugPrintln(3, WiFi.channel());
	//  DebugPrintln(3, actconf.apchannel);
	DebugPrint(3, "Max AP connections: ");
	DebugPrintln(3, actconf.maxconnections);

	hname = String(actconf.hostname) + "-" + String(actconf.sensorID);
	WiFi.hostname(hname);   // Provide the hostname
	DebugPrint(3, "Host name: ");
	DebugPrintln(3, hname);
	if (actconf.mDNS == 1) {
		MDNS.begin(hname);      // Start mDNS service
		MDNS.addService("http", "tcp", actconf.httpport);       // HTTP service
		MDNS.addService("nmea-0183", "tcp", actconf.dataport); // NMEA0183 dada service for AVnav
	}
	DebugPrintln(3, "mDNS service: activ");
	DebugPrint(3, "mDNS name: ");
	DebugPrint(3, hname);
	DebugPrintln(3, ".local");

	// Start update server
	httpUpdater.setup(&httpServer);
	httpServer.begin();
	DebugPrint(3, "HTTP Update Server started at port: ");
	DebugPrintln(3, actconf.httpport);
	DebugPrint(3, "Use this URL: ");
	DebugPrint(3, "http://");
	DebugPrint(3, WiFi.softAPIP());
	DebugPrintln(3, "/update");
	DebugPrintln(3, "");

#include "ServerPages.h"    // Webserver pages request functions

	// Connect to WiFi network
	DebugPrint(3, "Connecting WiFi client to ");
	DebugPrintln(3, actconf.cssid);

	// Load connection timeout from configuration (maxccount = (timeout[s] * 1000) / 500[ms])
	maxccounter = (actconf.timeout * 1000) / 500;

	// Wait until is connected otherwise abort connection after x connection trys
	WiFi.begin(actconf.cssid, actconf.cpassword);
	ccounter = 0;
	while ((WiFi.status() != WL_CONNECTED) && (ccounter <= maxccounter)) {
		delay(500);
		DebugPrint(3, ".");
		ccounter++;
	}
	DebugPrintln(3, "");
	if (WiFi.status() == WL_CONNECTED) {
		DebugPrint(3, "WiFi client connected with IP: ");
		DebugPrintln(3, WiFi.localIP());
		DebugPrintln(3, "");
		digitalWrite(ledPin, HIGH);           // LED off (Low activ)

		delay(100);
	} else {
		WiFi.disconnect(true);                // Abort connection
		DebugPrintln(3, "Connection aborted");
		DebugPrintln(3, "");
		for (int i = 0; i <= 5; i++) {
			digitalWrite(ledPin, HIGH);         // LED off (Low activ)
			delay(100);
			digitalWrite(ledPin, LOW);          // LED on (Low activ)
			delay(100);
		}
	}

	// Start the NMEA TCP server
	server.begin();
	DebugPrint(3, "NMEA-Server started at port: ");
	DebugPrintln(3, actconf.dataport);
	// Print the IP address
	DebugPrint(3, "Use this URL : ");
	DebugPrint(3, "http://");
	if (WiFi.status() == WL_CONNECTED) {
		DebugPrintln(3, WiFi.localIP());
	} else {
		DebugPrintln(3, WiFi.softAPIP());
	};

	//*************************************************
	timer1_attachInterrupt(counter);          // Start interrupt routine counter
	timer1_enable(TIM_DIV16, TIM_EDGE, TIM_LOOP); // 80MHz / 16 => 0,2us
	timer1_write(500);                            // Start timer1 100us @ 0,2us
	Timer2.attach_ms(50, buildaverage); // Start timer all 50ms for average building and reading magnetic sensor
	Timer3.attach_ms(SendPeriod, sendNMEA);  // Data transmission timer for NMEA
	Timer4.attach_ms(RedSendPeriod, sendNMEA2); // Data transmission timer with reduced frequence for NMEA
	Timer5.attach_ms(500, winddata); // Start Timer all 500ms for wind data calculation

	// Work around for start problem by high wind speed > 7rpm (cyclic boot loop)
	// Start interrupts at first in low level mode and wait 4s then change in falling slope mode
	attachInterrupt(INT_PIN1, interruptRoutine1, LOW); // Start interrupt for wind speed
	attachInterrupt(INT_PIN2, interruptRoutine2, LOW); // Start Interrupt for wind direction
	delay(4000);
	// Start interrupts in falling slope modeserver
	attachInterrupt(INT_PIN1, interruptRoutine1, FALLING); // Start interrupt for wind speed
	attachInterrupt(INT_PIN2, interruptRoutine2, FALLING); // Start Interrupt for wind direction

	//**************************************************

	// Reset the time variables
	time1 = 0;
	time2 = 0;
	time1_avg = 0;
	time2_avg = 0;

}

//*********************************************************************************************
// Loop section
//*********************************************************************************************
void loop() {

	if (server.hasClient()) {
		//find free/disconnected spot
		int k;
		for (k = 0; k < maxTCPclients; k++)
			if (!serverClients[k]) { // equivalent to !serverClients[i].connected()
				serverClients[k] = server.available();
				DebugPrintln(3, "New client: index ");
				DebugPrintln(3, k);
				break;
			}

		//no free/disconnected spot so reject
		if (k == maxTCPclients) {
			server.available().println("---busy---");
			// hints: server.available() is a WiFiClient with short-term scope
			// when out of scope, a WiFiClient will
			// - flush() - all data will be sent
			// - stop() - automatically too
			DebugPrint(2,
					printf("server is busy with %d active connections\n",
							maxTCPclients));
		}
	}

	httpServer.handleClient();     // HTTP Server-handler for HTTP update server

	if (WiFi.status() != WL_CONNECTED) {
		digitalWrite(ledPin, LOW);      // LED on (Low activ)
	}

//
//		digitalWrite(ledPin, HIGH);     // LED off (Low activ)
//

	if (actconf.mDNS == 1) {
		MDNS.update();                // Update DNS info
	}

	// Wind speed and wind direction data calculated via Timer5 interrupt all 500ms

	// Sending NMEA data with normal speed
	if (windspeed_mps > 0 && flag1 == true) {

		DebugPrintln(3, "");
		DebugPrintln(3, "Send package:");

		if ((int(actconf.serverMode) == 0) || (int(actconf.serverMode) == 1)
				|| (int(actconf.serverMode) == 4)) {
			if (int(actconf.windSensor) == 1) {

				for (int j = 0; j < maxTCPclients; j++) {

					serverClients[j].println(sendMWV(1));
					serverClients[j].println(sendVWR(1));

				}

			}
			if (int(actconf.tempSensor) == 1) {
				if (String(actconf.tempSensorType) == "DS18B20") {
					for (int j = 0; j < maxTCPclients; j++) {

						serverClients[j].println(sendWST(1));

					}

				}
				if (String(actconf.tempSensorType) == "BME280") {
					for (int j = 0; j < maxTCPclients; j++) {

						serverClients[j].println(sendMDA(1));

					}

				}
			}
		}

		flashLED(10);                 // Flash LED for data transmission
		flag1 = false;                // Reset the flag
	}

	// Sending NMEA data with reduced speed
	if (windspeed_mps <= 0 && flag2 == true) {

		DebugPrintln(3, "");
		DebugPrintln(3, "Send package:");

		if ((int(actconf.serverMode) == 0) || (int(actconf.serverMode) == 1)
				|| (int(actconf.serverMode) == 4)) {
			if (int(actconf.windSensor) == 1) {
				for (int j = 0; j < maxTCPclients; j++) {

					serverClients[j].println(sendMWV(1));
					serverClients[j].println(sendVWR(1));

				}

			}
			if (int(actconf.tempSensor) == 1) {
				if (String(actconf.tempSensorType) == "DS18B20") {
					for (int j = 0; j < maxTCPclients; j++) {

						serverClients[j].println(sendWST(1));

					}

				}
				if (String(actconf.tempSensorType) == "BME280") {
					for (int j = 0; j < maxTCPclients; j++) {

						serverClients[j].println(sendMDA(1));

					}

				}
			}
		}

		flashLED(10);                 // Flash LED for data transmission
		flag2 = false;                // Reset the flag
	}

	//}
	delay(150);                       // Delay for load reducing
}

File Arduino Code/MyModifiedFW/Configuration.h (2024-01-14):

#ifndef Configuration_h
#define Configuration_h

// Default configuration
// Types 'byte' und 'word' doesn't work!
typedef struct {
  int valid = 2;                            // Number of configuration (Please change when the structure or values are changed)
  int crypt = 0;                            // Activate for critical webside a password query [0 = off|1 = on]
  char password[31] = "12345678";           // Password for critical websides (settings, update and reboot)
  char devname[21] = "Windsensor";          // Device name for web configuration
  char crights[14] = "NoWa (C) 2021";       // Copy rights
  char fversion[6] = "V1.15";               // Firmware version
  char license[12] = "GNU GPL V3";          // License type
  int debug =0 ;                            // Debug mode 0=off 1=Errors 2=Errors + Warnings 3=Errors + Warnings + Messages
  char cssid[31] = "WiFiClient";                // SSID of WiFi Client
  char cpassword[31] = "12345678";        // Password of WiFi Client
  int timeout = 30;                         // Connection timeout for client in [s] [30|90|120|150|180|210|240|270|300]
  char sssid[31] = "NoWa";                  // SSID of WiFi Server
  char spassword[31] = "12345678";          // Password of WiFi Server
  int apchannel = 9;                        // Assess Point channel [1...13]
  int maxconnections = 4;                   // Max number of connection for WiFi clients [1...4]
  int mDNS = 0;                             // Using mDNS service [0|1] 0=off, 1=on
  char hostname [31] = "windsensor";        // Hostname WiFi Server
  int dataport = 6666;                      // Port for NMEA data output
  int httpport = 80;                        // Port for HTTP and update pages
  int serverMode = 0;                       // Used server mode [0|1|2|3|4] 0=HTTP (JSON, NMEA), 1=NMEA Serial, 2=MQTT, 3=Diagnostic, 4=Demo (Simulation data)
  int serspeed = 115200;                    // Serial speed in [Bd] 8N1 [300|1200|2400|4800|9600|19200|38400|57600|74880|115200]
  int skin = 0;                             // Skin for websides [0|1|2]
  char instrumentType[8] = "complex";       // Instrument type [simple|complex] simple = Canvas HTML5 , complex = Canvas Steel Series library
  int instrumentSize = 400;                 // Instrument size X * Y [pix] [200|250|300|350|400|450|500|550|600]
  int sensorID = 0;                         // ID of sensor [0...9]
  char windSensorType[10] = "Yachta";    // Type of wind sensor [WiFi 1000|Yachta|Jukolein|Ventus]
  int windSensor = 1;                       // Send wind data 0=off 1=on (WIMWV, WIVWR, WIVPW, PWINF) or Serial or JSON
  char windType[2] = "R";                   // Type of wind R=relative, T=true
  int offset = 0;                           // Offset of wind direction [-180°...+180°]
  int average = 1;                          // Number of values for average building [1...10], for high speed use 1, default use 2
  char speedUnit[5] = "kn";                 // Unit of speed [m/s|km/h|kn|bft] for WIMWV
  int downWindSensor = 0;                   // Send data to down wind 0=off 1=on (WIVPW)
  int downWindRange = 50;                   // Down wind area = 180° +/- downWindRange
  float calslope = 1.0;                     // Speed sensor calibration slope, default 1.0
  float caloffset = 0.0;                    // Speed sensor calibration offset, default 0.0
  char tempSensorType[10] = "BME280";          // Type of temperature sensor [Off|DS18B20|BME280]
  int tempSensor = 1;                       // Send data for temp 0=off 1=on (PWWST)
  char tempUnit[2] = "C";                   // Unit of temperature [C|F]
} configData;

#endif

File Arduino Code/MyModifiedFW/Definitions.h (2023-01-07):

#ifndef Definitions_h
#define Definitions_h           

// Passwort settings
String transactionID = String(random(0, 99999999));// Generate a random transaction ID by initialisation
String raw = "";                  // Uncrypted raw data
String crypt = "";                // Crypted data

// EEPROM settings (max size is 4096 Byte)
int cfgStart = 1024;              // Start adress in EEPROM (Attention! The first 32 Byte are used beginning with adress 0)
int sizeEEPROM = 2048;            // Used size of EEPROM 2kB (limit for config file size)

// WLAN client settings
String hname;                     // Hostname
int maxccounter;                  // Maximum number for connection tests until aborted (maxcounter = 60; 60 * 500ms = 30s waiting time)
int ccounter;                     // Actual connection test counter

// Settings for NMEA server 
int SendPeriod = 500;            // SendPeriod in [ms], Attention! Range is limited [500...2000]
int RedSendPeriod = 2000;         // Reduced send period [ms] when wind speed is zero, range [2000...10000]
volatile bool flag1 = false;      // Flag for data sending (normal speed)
volatile bool flag2 = false;      // Flag for data sending (reduced speed)
volatile bool flag3 = false;      // Flag for zero wind speed detection (true = zero)

// Pin definitions WiFi 1000 wind sensor (default)
int ledPin = 2;                   // LED low activ GPIO 2 (D4)
int INT_PIN1 = 5;                 // Wind speed GPIO 5 (Hall sensor) (D1)
int INT_PIN2 = 4;                 // Wind direction GPIO 4 (Hall sensor) (D2)
int ONE_WIRE_BUS = 12;            // 1Wire bus on GPIO 12 (D6)

// I2C definitions
int i2creadyAS5600 = 0;           // Result of I2C scan for AS5600
byte i2cAddressAS5600 = 0x36;     // I2C address AS5600
int i2creadyBME280 = 0;           // Result of I2C scan for BME280
byte i2cAddressBME280 = 0x76;     // I2C address BME280
#define SEALEVELPRESSURE_HPA (1013.25)// Sea level air pressure


// Measuring data (used in interrupt)
volatile int marker1 = 0;         // Wind speed
volatile int marker2 = 0;         // Wind direction
volatile int marker3 = 0;         // Marker for data saving in a array (sensor 1 and 2 binary switching data)
volatile int scounter = 0;        // Array counter for data saving (sensor1 and 2)
volatile int rpcounter = 0;       // Raw pulse counter for wind direction sensor (per revolution)
volatile int pcounter = 0;        // Pulse counter for wind direction sensor (per revolution)
volatile unsigned long icounter = 0;    // Interrupt counter for rotation detection
volatile unsigned long icounterold = 0; // Old interrupt counter for rotation detection
volatile unsigned long counter1;  // Wind spped
volatile unsigned long counter2;  // Wind direction
volatile float time1;             // Wind speed (time in [ms] for one rotation)
volatile float time2;             // Wind direction (time in [ms] between wind speed sensor and wind direction sensor)
volatile int average;             // Number of values for average calculation [1...10]
volatile float timearray1[10];    // Array1 of time values (average building)
volatile float timearray2[10];    // Array2 of time values (average building)
volatile int mc = 0;              // Modulo counter
volatile float time1_avg;         // Average wind speed (time in [ms] for one rotation)
volatile float time2_avg;         // Average direction (time in [ms] between wind speed sensor and wind direction sensor)

static float radius = 0.06;       // Radius between center and middle of half hemisphere position (WiFi 1000)
//static float radius2 = 0.043;     // Radius between center and middle of half hemisphere position (Yachta|Jukolein)
static float radius2 = 0.052;
static float radius3 = 0.055;     // Radius between center and middle of half hemisphere position (Ventus)
static float lamda = 0.3;         // Lambda is a constant for amemometer type with 3 hemisphere, lamda = 0,3
static float pi = 3.14159265358979;   // Pi constant
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

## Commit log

2023-01-07 Initial commit from eclipse
    [Configuration.h, Cups.STL, Fuss_regler.STL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]
2024-01-14 Esp kept disconnecting after a while. I added WiFi.setSleepMode(WIFI_NONE_SLEEP); so it doesn't sleep
    [Configuration.h]
